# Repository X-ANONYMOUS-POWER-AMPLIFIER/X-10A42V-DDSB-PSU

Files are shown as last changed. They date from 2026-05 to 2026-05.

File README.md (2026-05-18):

# X-10A42V-DDSB-PSU - DUAL IN ONE 10A 42V DC SYMMETRICAL PSU FOR POWER AMPLIFIER IN DOUBLE-SIDED CIRCUIT BOARD

X-10A42V-DDSB-PSU is a dual in one PSU circuit module in one double-sided circuit board designed to supply the operating voltage for power amplifier main-circuit module such as [X-B120W-4](https://github.com/X-ANONYMOUS-POWER-AMPLIFIER/X-B120W-4) and/or [X-B120W-4-LITE](https://github.com/X-ANONYMOUS-POWER-AMPLIFIER/X-B120W-4-LITE). It provides split dual 42V DC symmetrical outputs with 10A DC current handling capability applies GBU1006 rectifier diodes, 12V DC non-symmetrical output, and 15V DC symmetrical outputs.

This PSU circuit module provides advanced groundings specialized for power amplifier as: audio grounds, power/PSU grounds, and chassis grounds. It is completed with inrush current limiter applies 7 ohms - 15 Amperes Inrush Current Limiter (NTC Thermistor) type MS32-7R015 product from Vishay / Ametherm. It also completed with AC power entry socket PCB that can be applied for Bulgin AC Power Entry Modules Flange Mount IEC Fused Inlet model PF0002-28.

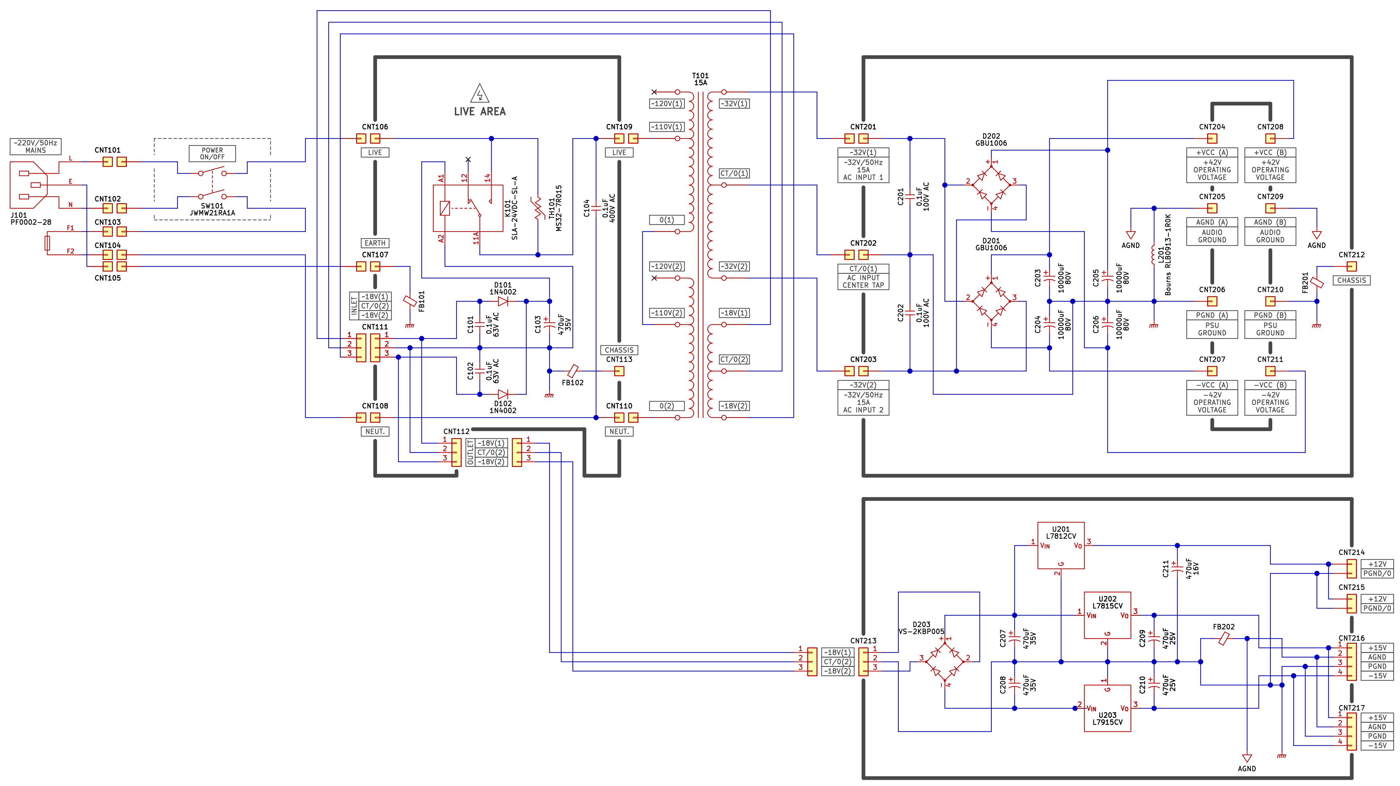
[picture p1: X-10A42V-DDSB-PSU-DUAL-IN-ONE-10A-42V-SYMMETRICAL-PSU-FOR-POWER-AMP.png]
X-10A42V-DDSB-PSU schematic diagram


Note about PCB:
The physical PCB can be split into 4 pieces by cutting on the breakaway-tabs.

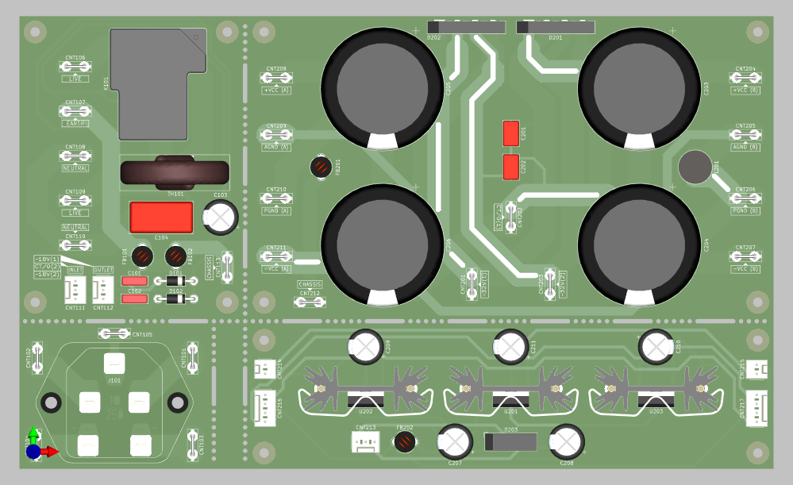
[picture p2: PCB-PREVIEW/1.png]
Circuit board preview 1

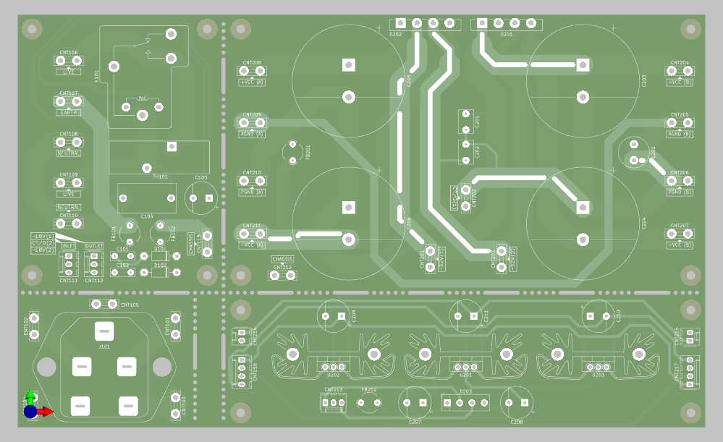
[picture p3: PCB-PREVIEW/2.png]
Circuit board preview 2

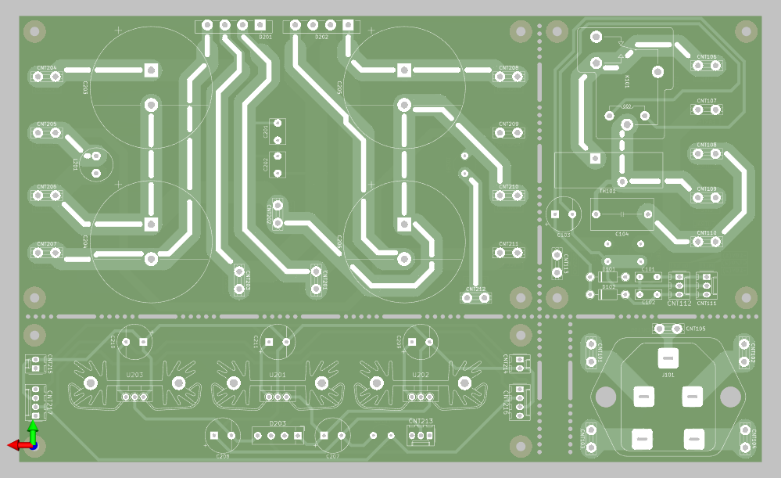
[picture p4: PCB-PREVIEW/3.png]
Circuit board preview 3

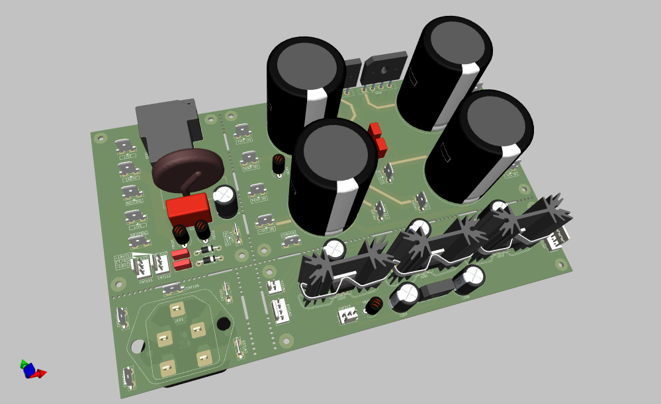
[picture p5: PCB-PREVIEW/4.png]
Circuit board preview 4

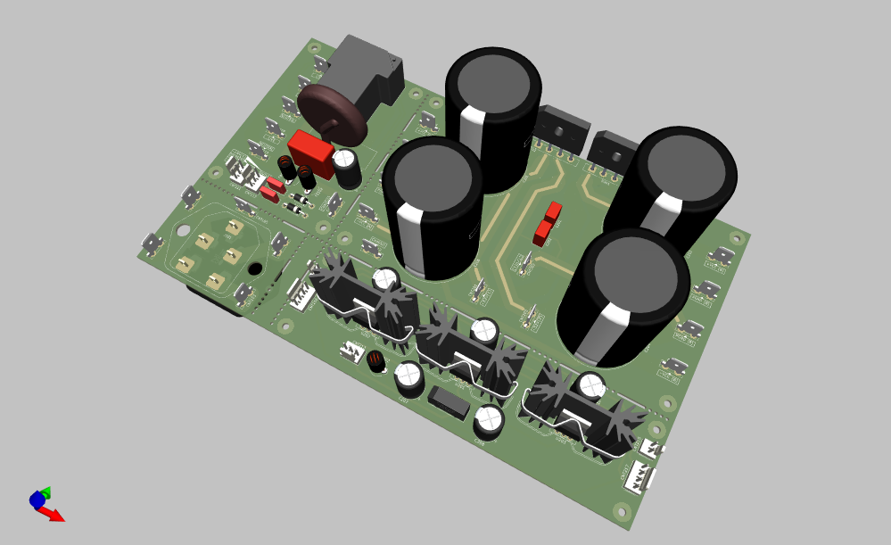
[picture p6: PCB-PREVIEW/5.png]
Circuit board preview 5

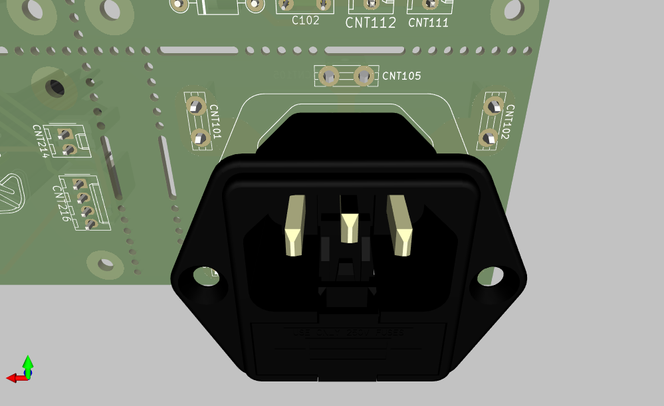
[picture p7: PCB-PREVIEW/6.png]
Circuit board preview 6

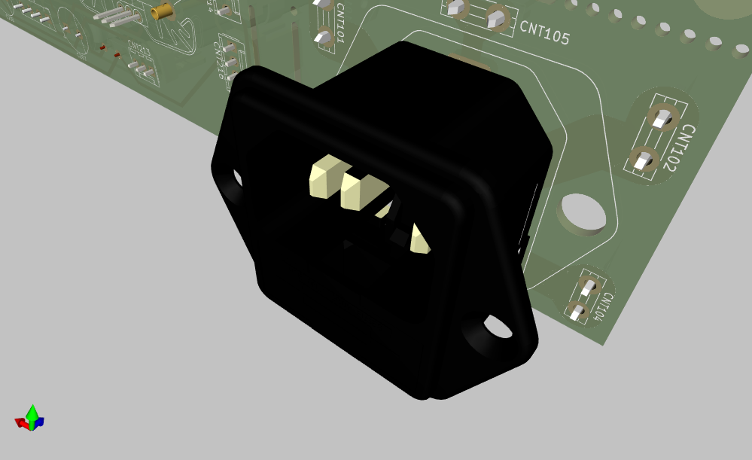
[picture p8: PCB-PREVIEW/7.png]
Circuit board preview 7

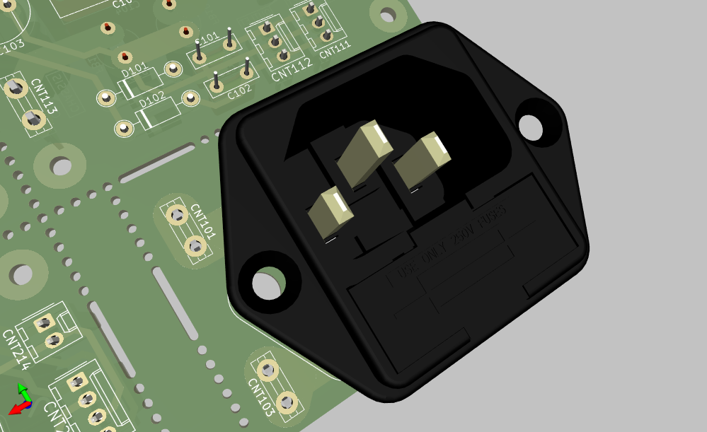
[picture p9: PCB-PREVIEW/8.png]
Circuit board preview 8


## License

1. **License Grant**  
The Licensor hereby grants you a worldwide, royalty-free, non-exclusive, perpetual license to use the circuit design for the non-commercial purposes only.
2. **Conditions**  
Attribution: You must provide credit to the original creator when distributing this circuit design.
3. **Disclaimer of Warranty**  
THE DESIGN IS PROVIDED "AS IS". THE LICENSOR MAKES NO WARRANTIES, EXPRESS OR IMPLIED, REGARDING THE DESIGN, INCLUDING BUT NOT LIMITED TO ANY IMPLIED WARRANTIES OF MERCHANTABILITY OR FITNESS FOR A PARTICULAR PURPOSE.
4. **Limitation of Liability**  
IN NO EVENT SHALL THE LICENSOR BE LIABLE FOR ANY DAMAGES, INCLUDING BUT NOT LIMITED TO DIRECT, INDIRECT, INCIDENTAL, OR CONSEQUENTIAL DAMAGES ARISING OUT OF THE USE OF THE DESIGN.

## Design Files Download

Design files bundle is available for download by follow the URL: [https://github.com/X-ANONYMOUS-POWER-AMPLIFIER/X-10A42V-DDSB-PSU/archive/refs/heads/main.zip](https://github.com/X-ANONYMOUS-POWER-AMPLIFIER/X-10A42V-DDSB-PSU/archive/refs/heads/main.zip)

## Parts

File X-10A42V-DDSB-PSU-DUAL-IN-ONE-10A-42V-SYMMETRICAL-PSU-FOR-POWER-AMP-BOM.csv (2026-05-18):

Reference | Value | Rating | Description | MFR Number | Manufacturer | Qty
C101,C102 | 0.1uF | 63V AC | Film Capacitors 0.1 uF 100 VDC 5% | MKS2D031001A00JC00 | WIMA | 2
C103,C207,C208 | 470uF | 35V | Aluminum Electrolytic Capacitors - Radial Leaded 470uF 35volts 10x16 LS 5mm | EEU-HD1V471 | Panasonic | 3
C104 | 0.1uF | 400V AC | Film Capacitors 0.1 uF 630 VDC 5% | MKP1J031004J00JI00 | WIMA | 1
C201,C202 | 0.1uF | 100V AC | Film Capacitors 0.1 uF 250 VDC 20% | MKS2F031001E00MSSD | WIMA | 2
C203,C204,C205,C206 | 10000uF | 80V | Aluminum Electrolytic Capacitors - Snap In 80volts 10000uF 85c 35x50x10L/S | LLS1K103MELC | Nichicon | 4
C209,C210 | 470uF | 25V | Aluminum Electrolytic Capacitors - Radial Leaded 470uF 35volts 10x16 LS 5mm | EEU-FC1E471L | Panasonic | 2
C211 | 470uF | 16V | Aluminum Electrolytic Capacitors - Radial Leaded 470uF 16V | ECA-1CM471 | Panasonic | 1
CNT101,CNT102,CNT103,CNT104,CNT105,CNT106,CNT107,CNT108,CNT109,CNT110,CNT113,CNT201,CNT202,CNT203,CNT204,CNT205,CNT206,CNT207,CNT208,CNT209,CNT210,CNT211,CNT212 | 2376582-2 |  | Terminals 250 FASTON PCB TAB TPBR, 2P | 2376582-2 | TE Connectivity | 23
CNT111,CNT112,CNT213 | 22-27-2031 |  | Headers & Wire Housings 3C STR HEADER W/FRLK | 22-27-2031 | Molex | 3
CNT214,CNT215 | 22-27-2021 |  | Headers & Wire Housings 2 POS HEADER | 22-27-2021 | Molex | 2
CNT216,CNT217 | 22-27-2041 |  | Headers & Wire Housings 4 POS HEADER | 22-27-2041 | Molex | 2
CNTX103,CNTX104,CNTX109,CNTX110,CNTX112,CNTX113,CNTX114,CNTX201,CNTX202,CNTX203,CNTX206,CNTX207,CNTX208 | 1-160304-8 |  | Terminals 250 SRS FASTON REC | 1-160304-8 | TE Connectivity | 13
CNTX111,CNTX204,CNTX205 | 10-11-2034 |  | Headers & Wire Housings CRIMP HOUSING 3P polarizing ramp | 10-11-2034 | Molex | 3
D101,D102 | 1N4002 |  | Rectifiers Diode, DO-41, 100V, 1A | 1N4002 | Diotec Semiconductor | 2
D201,D202 | GBU1006 |  | Bridge Rectifiers 10 Amp 100 Volt | GBU1006 | Vishay General Semiconductor | 2
D203 | VS-2KBP005 |  | Bridge Rectifiers 50 Volt 2.0 Amp | VS-2KBP005 | Vishay Semiconductors | 1
FB101,FB102,FB201,FB202 | Ferrite Bead |  | Axial Lead Ferrite Bead | 28C0236-0JW-10 | Laird | 4
J101 | PF0002-28 |  | AC Power Entry Modules Flange Mount IEC Fused Inlet | PF0002/28 | Bulgin | 1
K101 | SLA-24VDC-SL-A |  | SONGLE, SLA-1（T90-1）Relay | SLA-24VDC-SL-A | Songle | 1
L201 | Bourns RLB0913-1R0K |  | Power Inductors - Leaded 1uH 10% 7.45A Non-SHLD 8.5x12.5mm | RLB0913-1R0K | Bourns | 1
SW101 | JWMW21RA1A |  | Rocker Switches DPST TV5 RATED BLACK CAP HRZ MRK PNL SEA | JWMW21RA1A | NKK Switches | 1
T101 | 15A |  | Power Transformer, 15A / Input: 110V, 120V, 50Hz dual primary windings / Output: 32V AC with CT + 18V AC with CT |  |  | 1
TH101 | MS32-7R015 |  | Inrush Current Limiters ICL 7R 20% 15A 31MM B | MS327R015B | Ametherm | 1
U201 | L7812CV |  | Linear Voltage Regulators 12V 1.5A Positive | L7812CV | STMicroelectronics | 1
U202 | L7815CV |  | Linear Voltage Regulators 15V, 1.5A Positive voltage regulator IC | L7815CV | STMicroelectronics | 1
U203 | L7915CV |  | Linear Voltage Regulators 15V 1.5A Negative | L7915CV | STMicroelectronics | 1

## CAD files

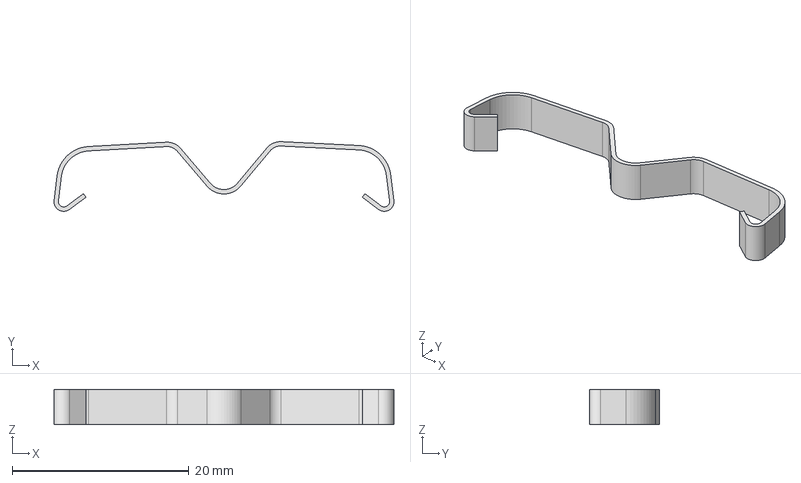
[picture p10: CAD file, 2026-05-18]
3D-FOOTPRINTS/thf_104.stp
38.5 x 7.89 x 4.00 mm

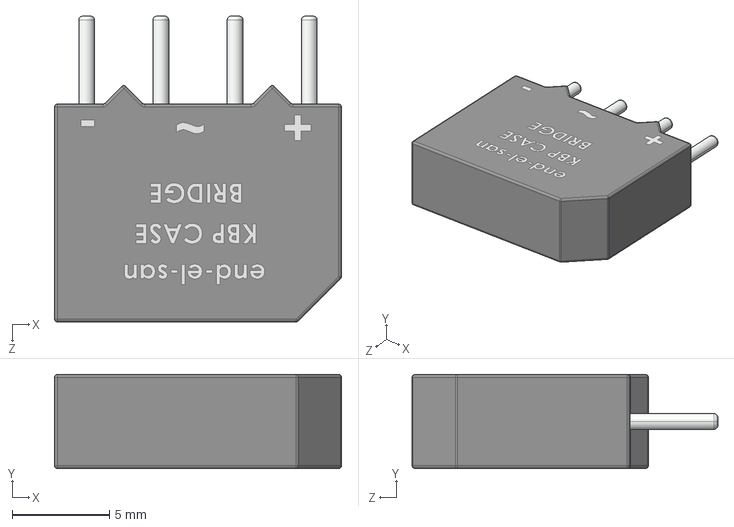
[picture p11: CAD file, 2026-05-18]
3D-FOOTPRINTS/Vishay-KBPM.STEP
14.7 x 4.83 x 15.7 mm

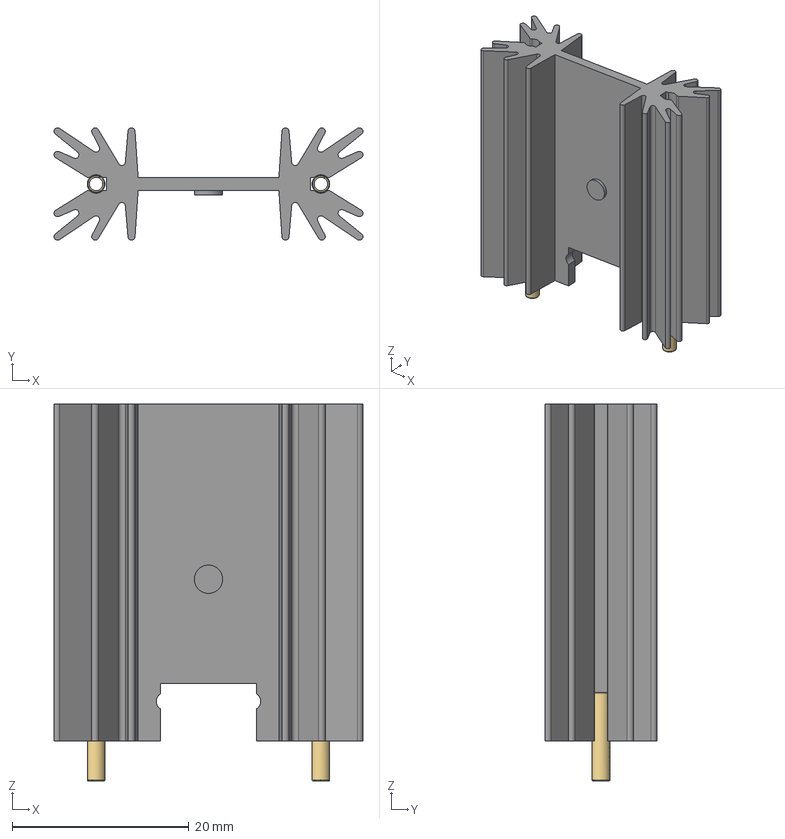
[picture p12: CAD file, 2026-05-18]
3D-FOOTPRINTS/sk_104_38.1_stc.stp
34.9 x 12.7 x 42.6 mm
A9001B20100008S x 2

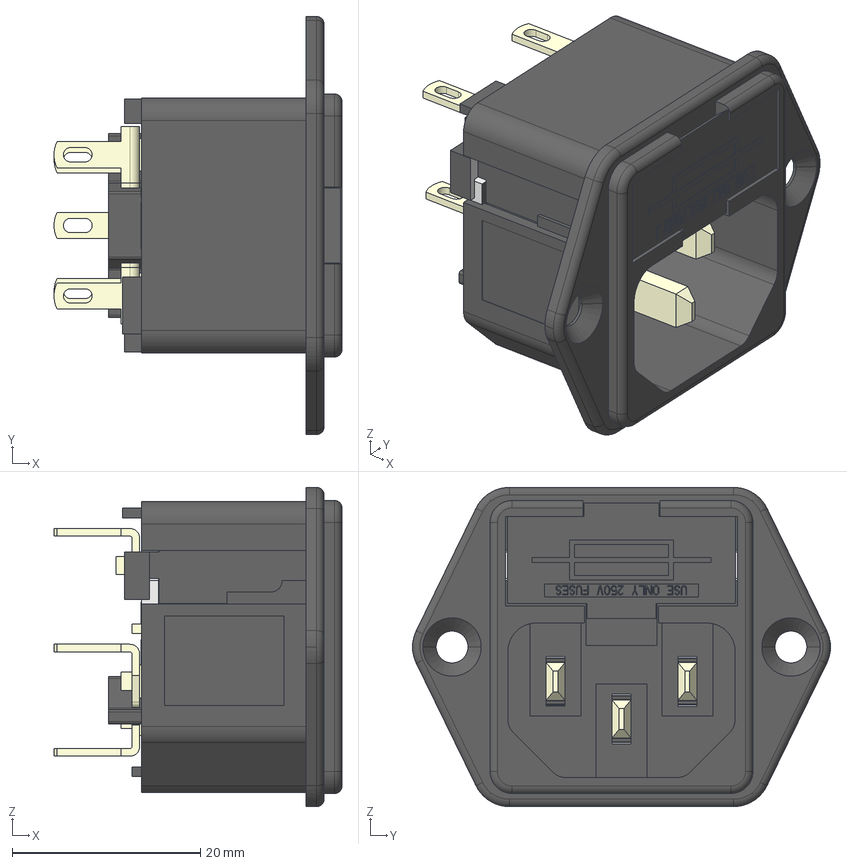
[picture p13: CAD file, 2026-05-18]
3D-FOOTPRINTS/BULGIN-IEC-Connector-PF0002-28.step
30.6 x 44.4 x 33.9 mm

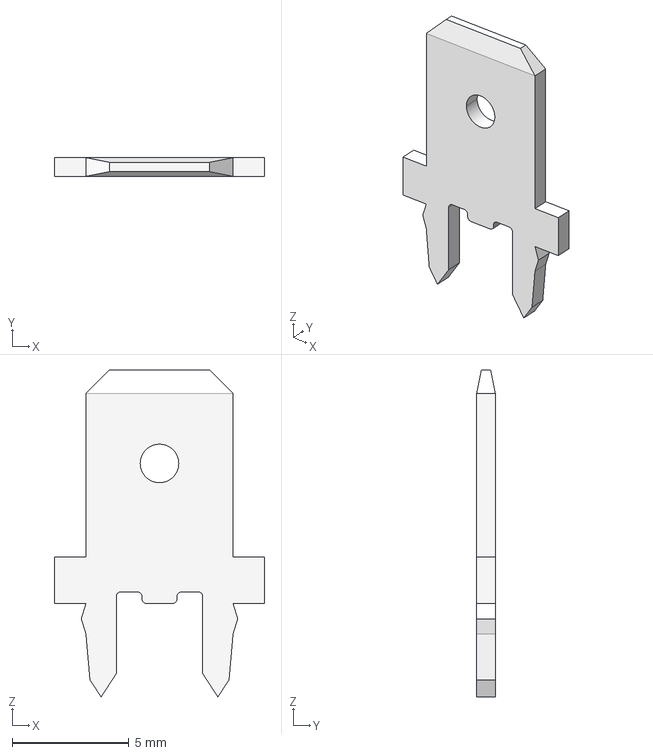
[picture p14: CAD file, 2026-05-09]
3D-FOOTPRINTS/c-2376582-2-a-3d.stp
9.00 x 0.8 x 14.0 mm

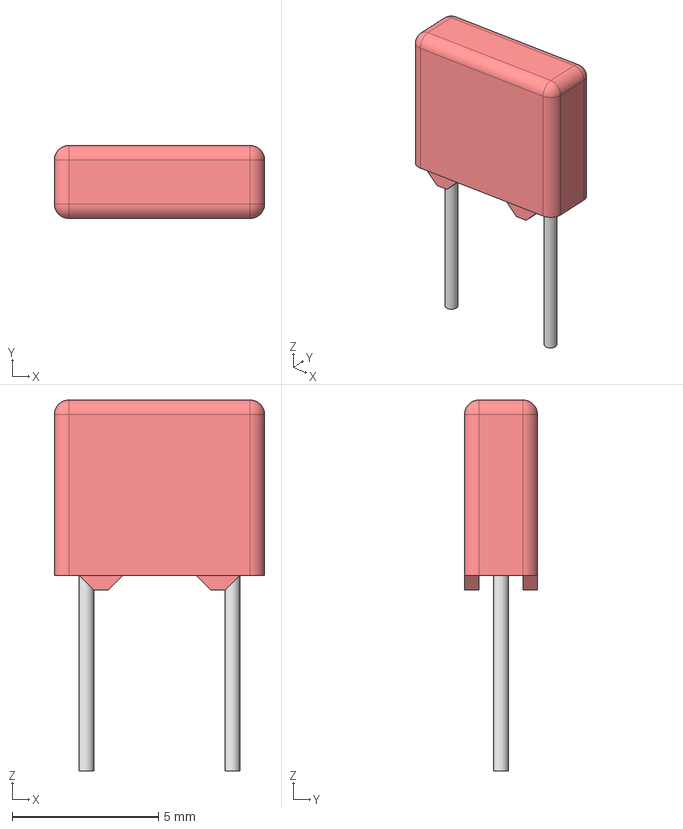
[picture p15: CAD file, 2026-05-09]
3D-FOOTPRINTS/FILM_RED_P500L720W250H650PD50.step
7.20 x 2.50 x 12.7 mm

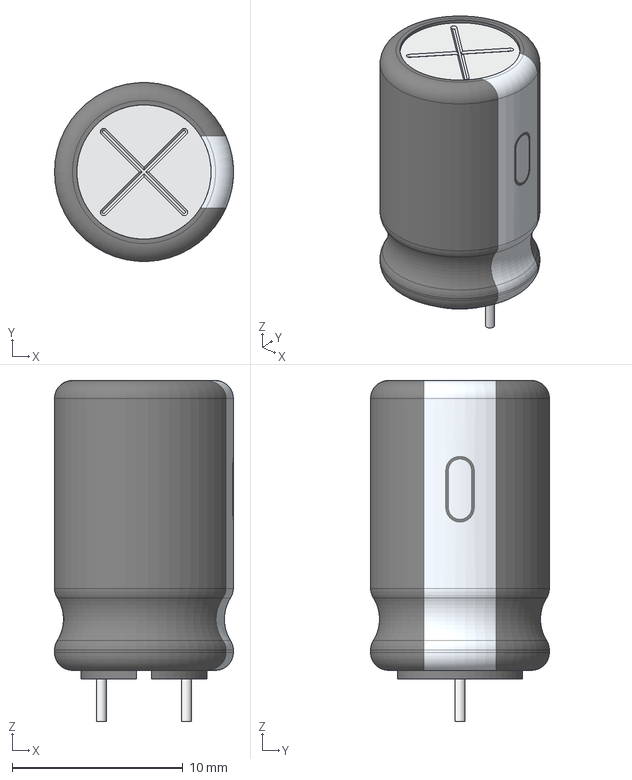
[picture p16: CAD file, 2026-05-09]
3D-FOOTPRINTS/CAP_RAD_D10x16_POL_BK.stp
10.5 x 10.5 x 20.0 mm

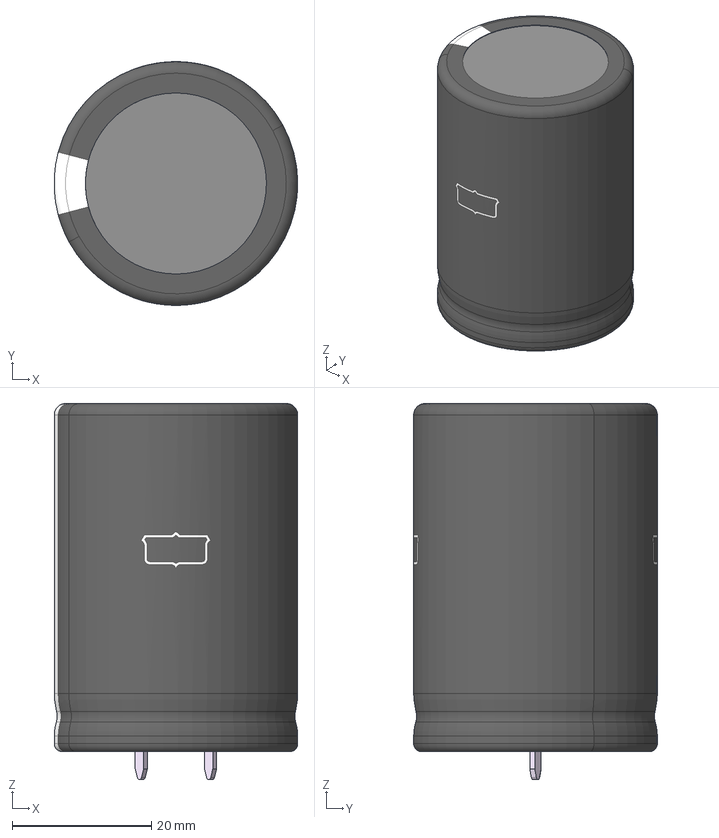
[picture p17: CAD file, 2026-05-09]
3D-FOOTPRINTS/E-SNAP-IN_D35_L50__VSN_SLEEVE_STRUCTURE.stp
35.0 x 35.0 x 54.0 mm
E-SNAP-IN_D35_L50_ELEMENT
E-SNAP-IN_VS_TERMINAL-
E-SNAP-IN_VS_TERMINAL+

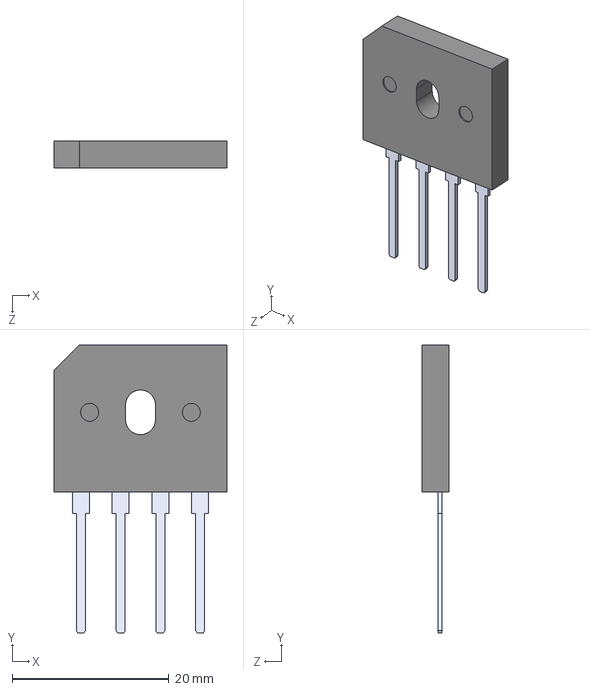
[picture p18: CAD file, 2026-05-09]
3D-FOOTPRINTS/GBU1006.STEP
22.1 x 36.8 x 3.43 mm

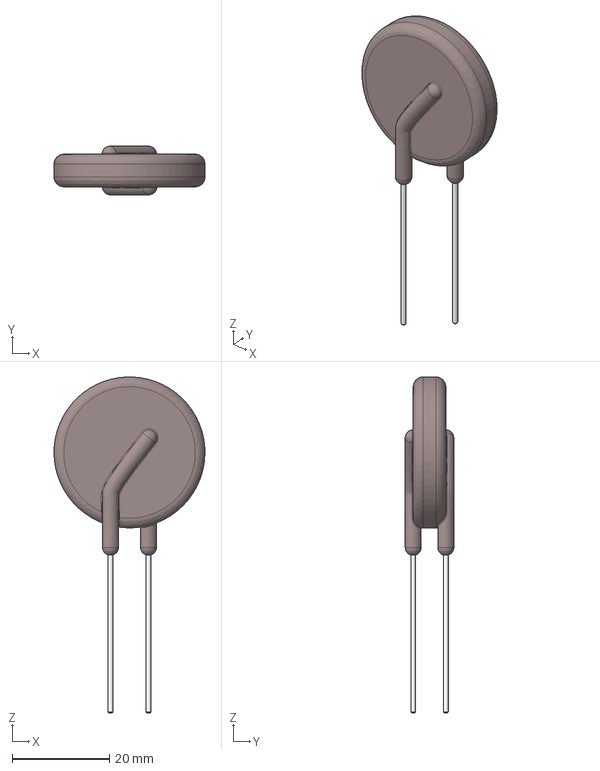
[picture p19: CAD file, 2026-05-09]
3D-FOOTPRINTS/NTC MS35 long leads v2.stp
31.0 x 10.0 x 69.0 mm

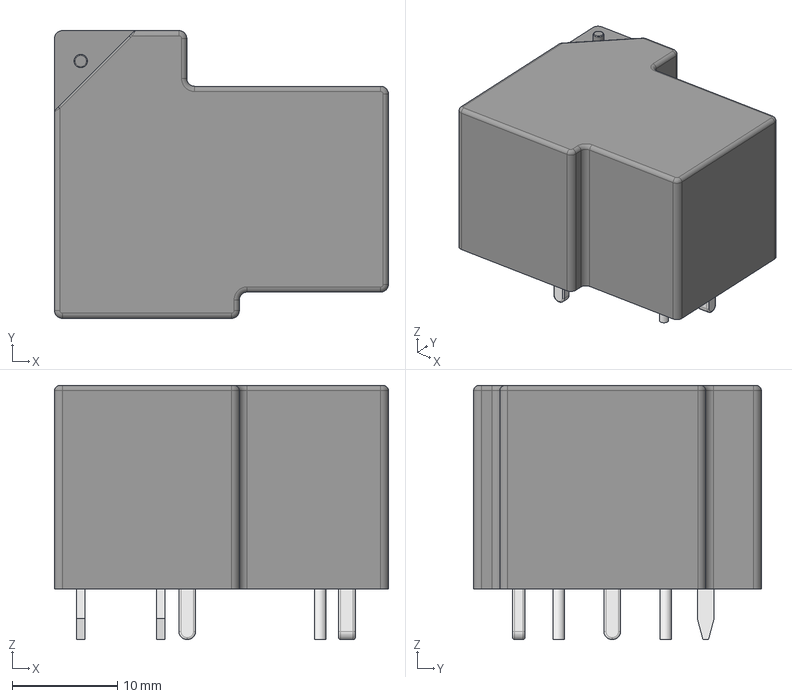
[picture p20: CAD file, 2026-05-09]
3D-FOOTPRINTS/Relay_SPDT_RAYEX-L90.step
31.8 x 27.4 x 24.2 mm
PIN1
PIN002
PIN003
PIN004
PIN006
PIN007

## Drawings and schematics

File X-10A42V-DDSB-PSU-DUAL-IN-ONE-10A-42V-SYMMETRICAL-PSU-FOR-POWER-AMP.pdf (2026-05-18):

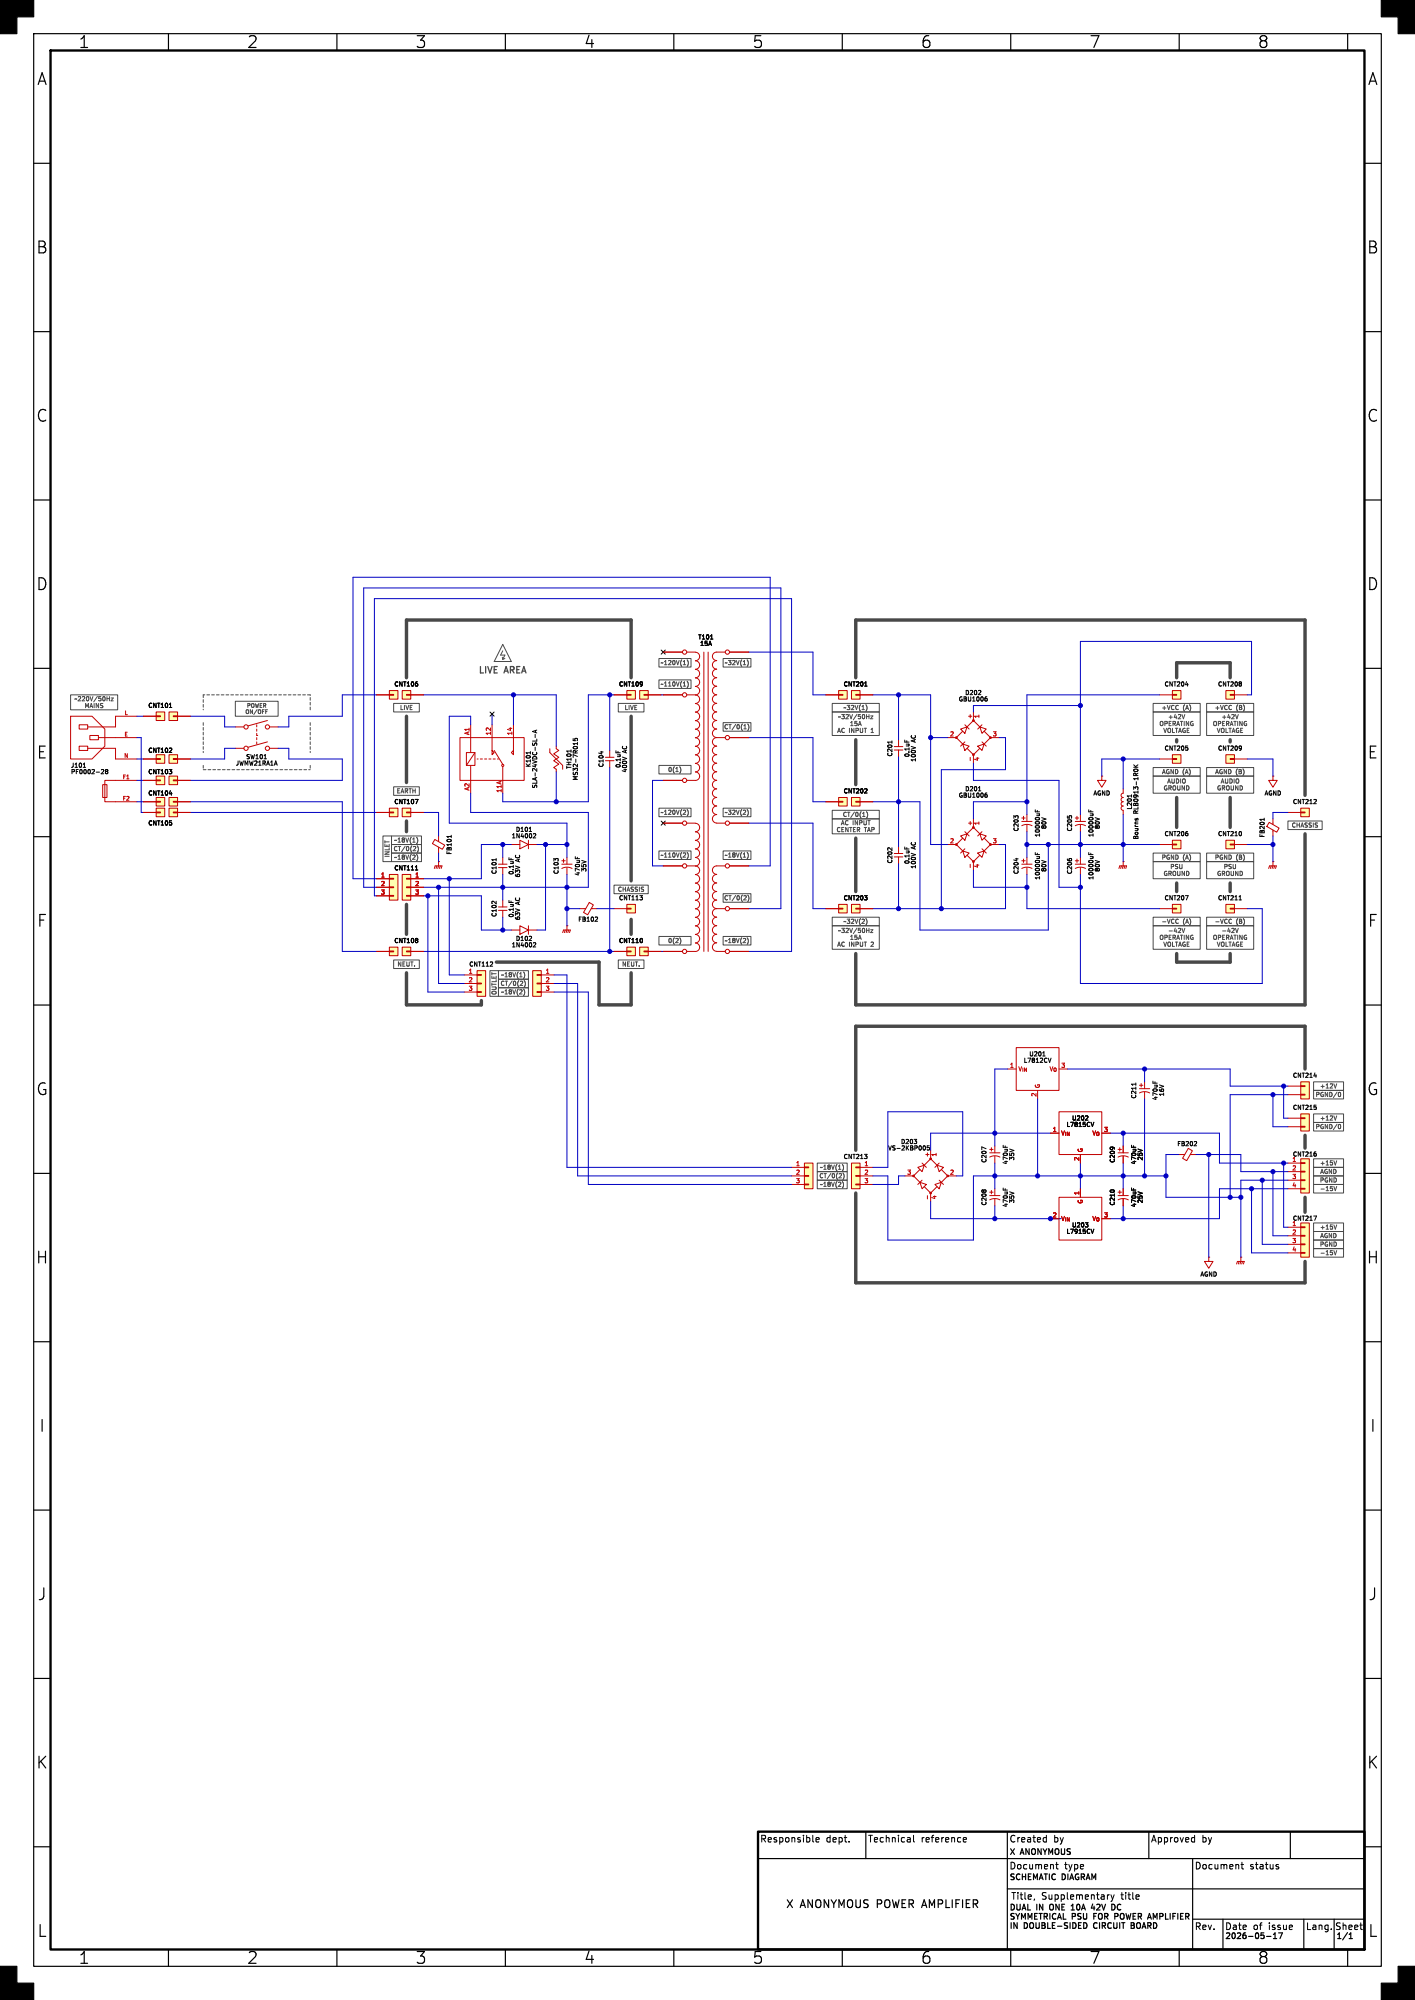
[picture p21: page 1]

X ANONYMOUS

SCHEMATIC DIAGRAM

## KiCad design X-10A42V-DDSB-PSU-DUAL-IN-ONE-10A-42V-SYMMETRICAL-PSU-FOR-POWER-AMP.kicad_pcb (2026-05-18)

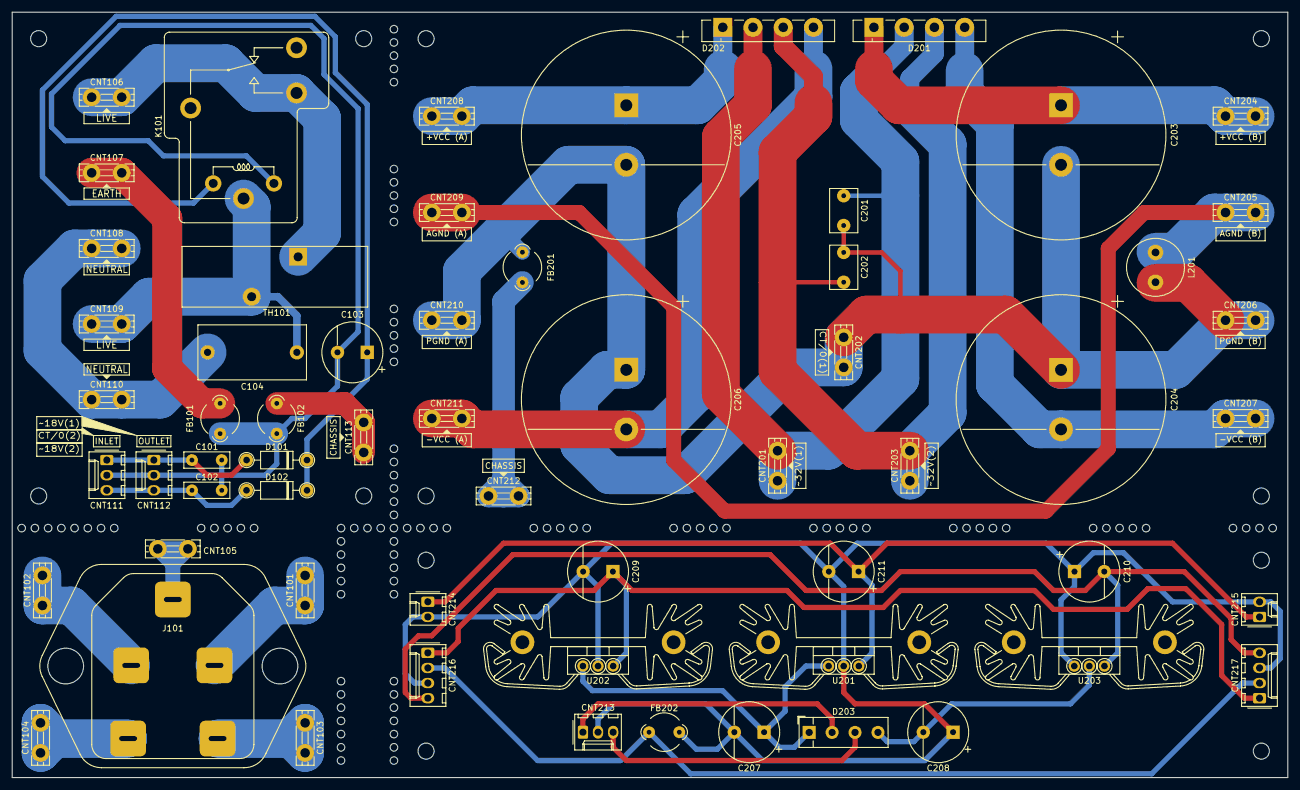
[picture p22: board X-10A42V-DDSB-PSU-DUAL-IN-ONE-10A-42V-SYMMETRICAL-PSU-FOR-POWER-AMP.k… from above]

Board: 2 copper layers, 214.3 x 128.6 mm, 61 parts (1 on the bottom side), 32 nets.

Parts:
C101, C102: 0.1uF; C_Rect_L7.5mm_W2.5mm_P5.00mm_WIMA_MKS2
C103, C207, C208, C209, C210, C211: 470uF; CP_Radial_D10.0mm_P5.00mm
C104: 0.1uF; C_Rect_L18.0mm_W9.0mm_P15.00mm_FKS3_FKP3
C201, C202: 0.1uF; C_Rect_L7.2mm_W4.5mm_P5.00mm_FKS2_FKP2_MKS2_MKP2
C203, C204, C205, C206: 10000uF; CP_Radial_D35.0mm_P10.00mm_3pin_SnapIn_Chemi-Con
CNT101, CNT102, CNT103, CNT104, CNT105, CNT106, CNT107, CNT108, CNT109, CNT110, CNT113, CNT201, CNT202, CNT203, CNT204, CNT205, CNT206, CNT207, CNT208, CNT209, CNT210, CNT211, CNT212: 2376582-2; PCB_TAB_250_FASTON_TPBR
CNT111, CNT112, CNT213: 22-27-2031; Molex_KK-254_AE-6410-03A_1x03_P2.54mm_Vertical
CNT214, CNT215: 22-27-2021; Molex_KK-254_AE-6410-02A_1x02_P2.54mm_Vertical
CNT216, CNT217: 22-27-2041; Molex_KK-254_AE-6410-04A_1x04_P2.54mm_Vertical
D101, D102: 1N4002; D_DO-41_SOD81_P10.16mm_Horizontal
D201, D202: GBU1006; Diode_Bridge_Vishay_GBU
D203: VS-2KBP005; Diode_Bridge_Vishay_KBPM
FB101, FB102, FB201, FB202: Ferrite Bead; LairdTech_28C0236-0JW-10
J101: PF0002-28; BULGIN-IEC-Connector-PF0002-28
K101: SLA-24VDC-SL-A; Relay_SPDT_RAYEX-L90
L201: Bourns RLB0913-1R0K; L_Radial_D9.5mm_P5.00mm_Fastron_07HVP
TH101: MS32-7R015; NTC_MS32_7R015
U201: L7812CV; TO-220-3_Vertical_Heatsink-SK-104_38.1mm
U202: L7815CV; TO-220-3_Vertical_Heatsink-SK-104_38.1mm
U203: L7915CV; TO-220-3_Vertical_Heatsink-SK-104_38.1mm

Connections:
AGND: CNT205.1, CNT209.1, L201.2
AGND2: CNT216.2, CNT217.2, FB202.1
EGND: C101.2, C102.1, C103.2, CNT111.2, CNT112.2, FB101.2, FB102.2, K101.A2
unnamed: CNT101.1, J101.L
unnamed: CNT102.1, J101.N
unnamed: CNT103.1, J101.F1
unnamed: CNT104.1, J101.F2
unnamed: CNT105.1, J101.E
unnamed: CNT106.1, K101.14, TH101.1
unnamed: CNT107.1, FB101.1
unnamed: C104.2, CNT108.1, CNT110.1
unnamed: C104.1, CNT109.1, K101.11A, TH101.2
unnamed: C101.1, CNT111.1, CNT112.1, D101.2 (A)
unnamed: C102.2, CNT111.3, CNT112.3, D102.2 (A)
unnamed: CNT113.1, FB102.1
unnamed: C201.1, CNT201.1, D201.2, D202.2
unnamed: C202.2, CNT203.1, D201.3, D202.3
unnamed: C203.1, CNT204.1, D201.1 (+)
unnamed: C204.2, CNT207.1, D201.4 (-)
unnamed: C205.1, CNT208.1, D202.1 (+)
unnamed: C206.2, CNT211.1, D202.4 (-)
unnamed: CNT212.1, FB201.1
unnamed: CNT213.1, D203.2
unnamed: CNT213.3, D203.3
unnamed: C211.1, CNT214.1, CNT215.1, U201.3 (V_{O})
unnamed: C209.1, CNT216.1, CNT217.1, U202.3 (V_{O})
unnamed: C210.2, CNT216.4, CNT217.4, U203.3 (V_{O})
unnamed: C103.1, D101.1 (K), D102.1 (K), K101.A1
unnamed: C207.1, D203.1 (+), U201.1 (V_{IN}), U202.1 (V_{IN})
unnamed: C208.2, D203.4 (-), U203.2 (V_{IN})
PGND: C201.2, C202.1, C203.2, C204.1, C205.2, C206.1, CNT202.1, CNT206.1, CNT210.1, FB201.2, L201.1
PGND2: C207.2, C208.1, C209.2, C210.1, C211.2, CNT213.2, CNT214.2, CNT215.2, CNT216.3, CNT217.3, FB202.2, U201.2 (G), U202.2 (G), U203.1 (G)
